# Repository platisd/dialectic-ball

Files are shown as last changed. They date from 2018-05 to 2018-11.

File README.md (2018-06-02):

# Dialectic Ball
Need to debug your code? Got stuck? Stack Overflow doesn't have the answer? Then ask Dialectic Ball!

dialectic ball

## What?
The Dialectic Ball is a physical, [Magic 8-ball](https://en.wikipedia.org/wiki/Magic_8-Ball) inspired, debugging tool for your daily code struggles! Once you are out of ideas, pick up the Dialectic Ball and explain the problem you are facing with all its details. Remember, the Dialectic Ball is a delicate and highly advanced piece of technology, thus the more information you provide it and the more you outline the problem with all its aspects, the better the chance it will be able to assist you.

Once you are done illustrating your coding issue to it, shake Dialectic Ball until the progress bar is filled and wait for the answer! If you do not get a satisfactory answer then try again. Clarify the problem better, think of any crucial details that you might have omitted during the previous run and shake again. Keep on it, until you get a witty response that helps you solve the problem!

The Dialectic Ball is more like a [rubber duck](https://en.wikipedia.org/wiki/Rubber_duck_debugging) than a [Magic 8-ball](https://en.wikipedia.org/wiki/Magic_8-Ball), so **do not ask it yes-no questions**. That wouldn't be so dialectic, would it? Of course, you can always easily modify the code and make it answer whatever you wish.

### Usage manual
1. Pick up the Dialectic Ball and face the screen
2. Admire the 8-ball intro logo
3. Dialectic Ball will prompt you to ask your question
4. Take your time and ask your question, providing all the necessary details
5. When you are done, shake the ball until the progress bar on the bottom is filled up
6. The solution to your problems is presented to you
7. If you are satisfied with the response, put the Dialectic Ball facing downwards
8. If the answer did not help, shake again when prompted

## Why?
Despite our [impressive rubber duck collection](https://i.imgur.com/bP3KeV4.jpg) at the office, sometimes they fall short on feedback and interaction. In such occasions we often utilize a colleague, but this is admittedly not the most productive use of our colleagues. Dialectic Ball intends to fill this gap, i.e. a rubber duck that is able to provide feedback. As a bonus, shaking it is fun!

## How?
Dialectic Ball is comprised of an ATtiny84, connected to a GY-61 module (based on the ADXL335 accelerometer) and an LCD screen like the ones used on the old NOKIA phones! Two AAA batteries are powering the gadget up and a [3D printed case](https://www.tinkercad.com/things/4zkr0X7OHBL) encompasses everything, giving it a hemispherical shape. The PCB that routes everything together was manufactured by [JLCPCB](https://jlcpcb.com/), who will make your prototype PCB's for just 2$ and were kind enough to sponsor the `rev. 0` boards.

From a software perspective the microcontroller mainly remains in deep sleep mode, periodically waking up to turn the accelerometer on and read its measurements. If necessary, the screen will also be powered up and the appropriate messages will be displayed to the user. Specifically, the system wakes up when the ball is not facing downwards. Furthermore, the particular LCD screen consumes minimal power, even when displaying graphics, which makes it ideal for low power applications. Overall, the average power consumption of the gadget is around 10μA, enabling it to remain operational for years on those two batteries. Last but not least, the display is controlled via the [Nokia LCD](https://github.com/platisd/nokia-5110-lcd-library) library.

### Components
* [Dialectic Ball PCB](https://github.com/platisd/dialectic-ball/tree/master/hardware/eagle)
* ATTiny84-20PU
* DIP-14 socket
* AAA battery holders (2)
* Nokia LCD screen (**Important**: Get ones that have [this](https://i.imgur.com/MhUsdiz.jpg) pin layout)
* GY-61 accelerometer module
* Tactile button
* 10KΩ resistor
* 330Ω resistor
* [3D printed case](https://www.tinkercad.com/things/4zkr0X7OHBL-magic8ball)

## Media
* [Article on platis.solutions](https://platis.solutions/blog/2018/06/02/debug-your-code-with-dialectic-ball/)
* [Demo video](https://youtu.be/oXdIgaYoSw0)

## Similar projects
* [Programmer's Magic 8-ball](https://github.com/FareedQ/Programmer-s-Magic-8-Ball)

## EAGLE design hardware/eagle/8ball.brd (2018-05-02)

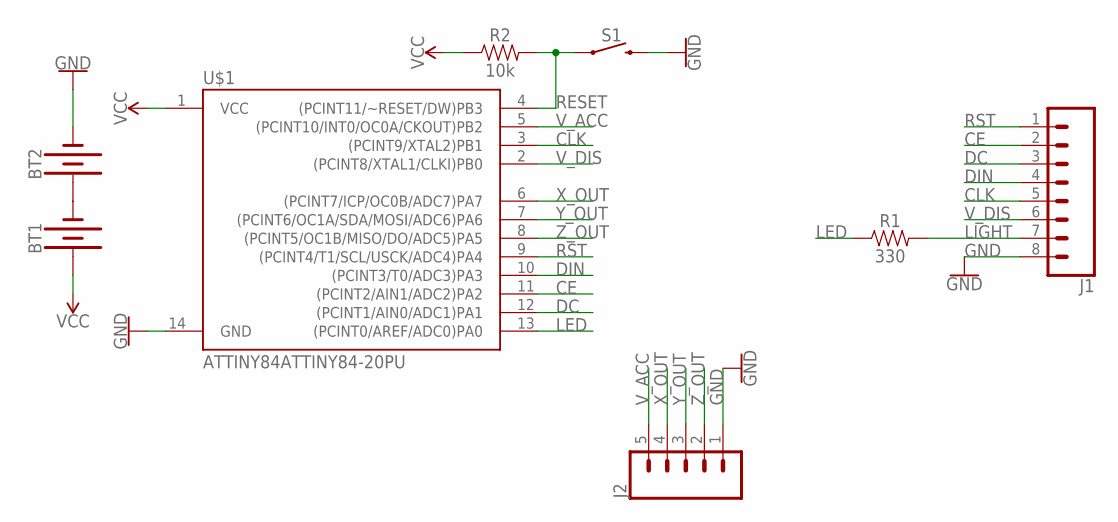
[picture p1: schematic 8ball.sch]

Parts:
BT1, BT2: BATTERY-AAA
J1: CONN_08FEMALE_LOCK; 1X08_FEMALE_LOCK
J2: CONN_05LOCK; 1X05_LOCK
R1: 330; AXIAL-0.3
R2: 10k; AXIAL-0.3
S1: MOMENTARY-SWITCH-SPST-PTH-6.0MM-KIT; TACTILE_SWITCH_PTH_6.0MM_KIT
U$1: ATTINY84ATTINY84-20PU; DIP14

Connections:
CE: J1.2, U$1.11 ((PCINT2/AIN1/ADC2)PA2)
CLK: J1.5, U$1.3 ((PCINT9/XTAL2)PB1)
DC: J1.3, U$1.12 ((PCINT1/AIN0/ADC1)PA1)
DIN: J1.4, U$1.10 ((PCINT3/T0/ADC3)PA3)
GND: BT2.GND@1 (-), J1.8, J2.1, S1.3 (2), U$1.14 (GND)
LED: R1.P$1 (1), U$1.13 ((PCINT0/AREF/ADC0)PA0)
LIGHT: J1.7, R1.P$2 (2)
unnamed: BT1.GND@1 (-), BT2.PWR@1 (+)
RESET: R2.P$2 (2), S1.1, U$1.4 ((PCINT11/~RESET/DW)PB3)
RST: J1.1, U$1.9 ((PCINT4/T1/SCL/USCK/ADC4)PA4)
VCC: BT1.PWR@1 (+), R2.P$1 (1), U$1.1 (VCC)
V_ACC: J2.5, U$1.5 ((PCINT10/INT0/OC0A/CKOUT)PB2)
V_DIS: J1.6, U$1.2 ((PCINT8/XTAL1/CLKI)PB0)
X_OUT: J2.4, U$1.6 ((PCINT7/ICP/OC0B/ADC7)PA7)
Y_OUT: J2.3, U$1.7 ((PCINT6/OC1A/SDA/MOSI/ADC6)PA6)
Z_OUT: J2.2, U$1.8 ((PCINT5/OC1B/MISO/DO/ADC5)PA5)

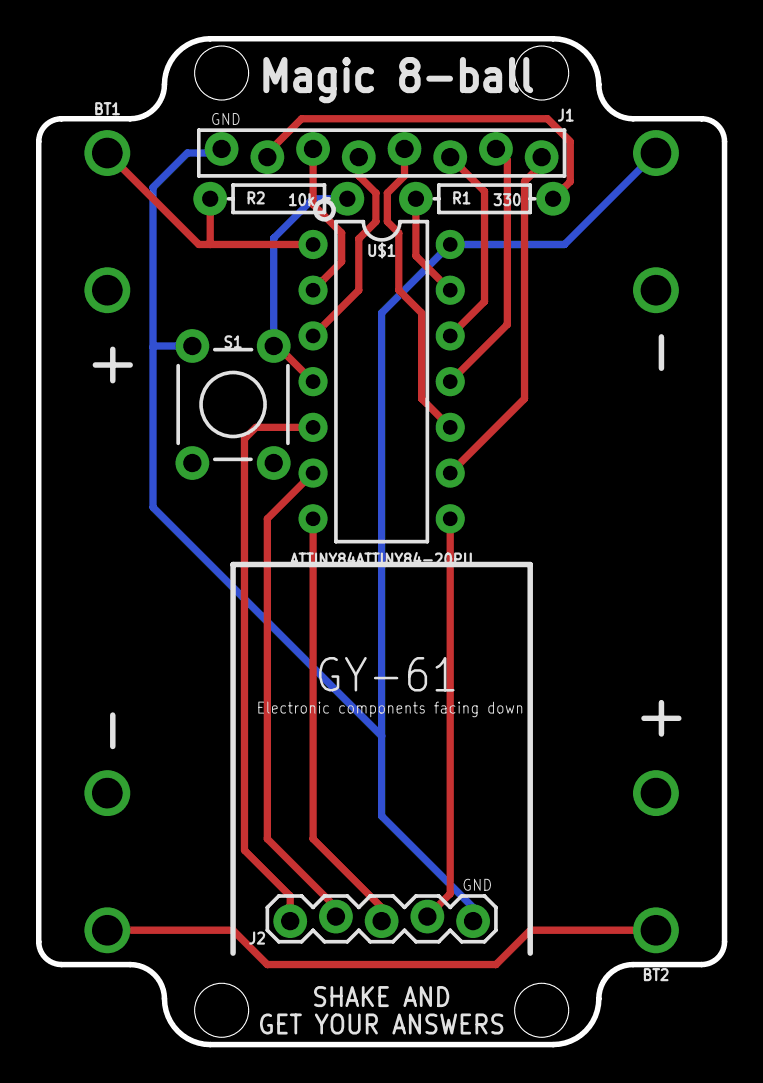
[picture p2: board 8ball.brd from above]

Board: 2 copper layers, 38.1 x 55.9 mm, 8 parts (0 on the bottom side), 16 nets.

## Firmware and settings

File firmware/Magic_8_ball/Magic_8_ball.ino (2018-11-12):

#include <Nokia_LCD.h>
#include <avr/sleep.h>
#include <avr/power.h>
#include <avr/wdt.h>
#include <avr/interrupt.h>
#include <avr/pgmspace.h>
#include <stdint.h>
#include "bitmaps.hpp"
#include "tips.hpp"

enum WatchDogTimeout {
  WDT_16ms = 0,
  WDT_32ms,
  WDT_64ms,
  WDT_128ms,
  WDT_250ms,
  WDT_500ms,
  WDT_1sec,
  WDT_2sec,
  WDT_4sec,
  WDT_8sec
};

enum RunningState {
  // Ball facing down for long amount of time
  // Screen is off
  // Slow check of accelerometer for changes
  DEEP_SLEEP,
  // Ball facing up
  // Screen is on - Waiting display
  // Fast check of accelerometer for changes
  IDLE_SCREEN,
  // Ball facing up
  // Screen is on - Game views
  // Faster check of accelerometer for changes
  PLAYING,
};

const uint8_t V_ACC_PIN = 8; // PB2
const uint8_t CLK_PIN = 9; // PB1
const uint8_t V_DIS_PIN = 10; // PB0
const uint8_t X_OUT_PIN = A7; // PA7
const uint8_t Y_OUT_PIN = A6; // PA6
const uint8_t Z_OUT_PIN = A5; // PA5
const uint8_t RST_PIN = 4; // PA4
const uint8_t DIN_PIN = 3; // PA3
const uint8_t CE_PIN = 2; // PA2
const uint8_t DC_PIN = 1; // PA1
const uint8_t LED_PIN = 0; // PA0

// Input & output pins directly controlled in this scope
const uint8_t OUTPUT_PINS[] = {V_ACC_PIN, V_DIS_PIN, LED_PIN};
const uint8_t INPUT_PINS[] = {X_OUT_PIN, Y_OUT_PIN, Z_OUT_PIN};
const uint8_t LCD_DATA_PINS[] = {CLK_PIN, DIN_PIN, DC_PIN, CE_PIN, RST_PIN};

// The experimentally determined Z-axis value over which we consider
// ourselves to be facing up
const unsigned int MIN_FACING_UP_THRESHOLD = 470;
// The minimum acceleration delta (on X,Y,Z axes) to be considered as a movement
// The smaller the number the easier a "movement" will be registered
const unsigned int MOVEMENT_ACCELERATION_THRESHOLD = 25; // Experimentally determined
// The amount of detected movements needed to start a game
const uint8_t AMOUNT_OF_MOVEMENTS_THRESHOLD = 5;
// How much to wait before using the accelerometer in milliseconds
const unsigned long ACCELEROMETER_BOOTUP_TIME = 15;
// Sleep duration while in DEEP_SLEEP mode
const unsigned long DEEP_SLEEP_INTERVAL = 1000;
// Sleep duration while in IDLE_SCREEN mode
const unsigned long IDLE_SCREEN_INTERVAL = 100;
// Sleep duration while in PLAYING mode
const unsigned long TIP_INTERVAL = 2500;
const uint8_t TIPS_LENGTH = 50; // The tips' max length in characters
const unsigned long EIGHTBALL_SLEEP = 500; // How long to display the 8ball logo in milliseconds

volatile bool watchdogBarked = false;

Nokia_LCD lcd(CLK_PIN /* CLK */, DIN_PIN /* DIN */, DC_PIN /* DC */, CE_PIN /* CE */, RST_PIN /* RST */);
RunningState currentState = DEEP_SLEEP;
unsigned int amountOfMovements = 0;
int previousAcceleration = 0;
bool justWokeUp = true; // A flag to indicate whether the screen is turning on just now

/**
  Watchdog interrupt routine to be triggered when watchdog times out.
*/
ISR(WDT_vect) {
  watchdogBarked = true;
}

/**
    Sets up watchdog to be triggered (once) after the specified time
    @param wdt  the watchdog timeout duration
*/
void triggerWatchDogIn(WatchDogTimeout wdt) {
  // Adopted from InsideGadgets (www.insidegadgets.com)
  byte timeoutVal = wdt & 7;
  if (wdt > 7) {
    timeoutVal |= (1 << 5);
  }
  timeoutVal |= (1 << WDCE);

  MCUSR &= ~(1 << WDRF);
  WDTCSR |= (1 << WDCE) | (1 << WDE); // Start timed sequence
  WDTCSR = timeoutVal;
  WDTCSR |= _BV(WDIE);
  wdt_reset(); // Pat the dog
}

/**
   A utility method to derive a watchdog timeout's duration
   @param wdt the watchdog timeout
   @return    the amount of milliseconds corresponding to a watchdog timeout
*/
unsigned long getTimeoutDuration(WatchDogTimeout wdt) {
  return 1 << (wdt + 4);
}

void goToSleep() {
  set_sleep_mode(SLEEP_MODE_PWR_DOWN);
  power_all_disable ();
  sleep_enable();
  sleep_cpu(); // Sleep here and wait for the interrupt
  sleep_disable();
  power_all_enable(); // power everything back on
}

/**
   Blocks and stays in deep sleep until the specified time has elapsed
   using the current watchdog timeout.
   @param sleepDuration     how long to stay in deep sleep in milliseconds
   @param timeoutInterval   the watchdog timeout interval
*/
void stayInDeepSleepFor(unsigned long sleepDuration, WatchDogTimeout timeoutInterval = WDT_16ms) {
  unsigned long sleepTime = 0;

  // Start by triggering the watchdog to wake us up every `timeoutInterval`
  triggerWatchDogIn(timeoutInterval);
  while (sleepTime <= sleepDuration) {
    // Sleep until an interrupt occurs (external, change or watchdog)
    goToSleep();
    // Verify we woke up because of the watchdog and not
    // a spurious wake up due to some other unrelated interrupt.
    if (watchdogBarked) {
      // Note down that we have processed the watchdog bark
      watchdogBarked = false;
      // Increase the time we have already slept
      sleepTime += getTimeoutDuration(timeoutInterval);
    }
  }
  wdt_disable(); // Disable watchdog so it stops barking
}

/*** Helper functions ***/
void turnScreenOn() {
  digitalWrite(V_DIS_PIN, HIGH);
}

void turnScreenOff() {
  digitalWrite(V_DIS_PIN, LOW);
  for (auto pin : LCD_DATA_PINS) {
    digitalWrite(pin, LOW);
  }
}

void turnBacklightOn() {
  digitalWrite(LED_PIN, LOW);
}

void turnBacklightOff() {
  digitalWrite(LED_PIN, HIGH);
}

void turnAccelerometerOn() {
  // Accelerometer needs some few milliseconds to get ready
  // so we need to make sure that we give it this time
  digitalWrite(V_ACC_PIN, HIGH);
  stayInDeepSleepFor(ACCELEROMETER_BOOTUP_TIME, WDT_16ms); // Give the accelerometer some time to boot
  enableADC();
}

void turnAccelerometerOff() {
  disableADC();
  digitalWrite(V_ACC_PIN, LOW);
}

unsigned int getAccelerationX() {
  return analogRead(X_OUT_PIN);
}

unsigned int getAccelerationY() {
  return analogRead(Y_OUT_PIN);
}

unsigned int getAccelerationZ() {
  return analogRead(Z_OUT_PIN);
}

unsigned int getAccelerationXYZ() {
  return getAccelerationX() + getAccelerationY() + getAccelerationZ();
}

void disableADC() {
  ADCSRA &= ~(1 << ADEN);
}

void enableADC() {
  ADCSRA |= (1 << ADEN);
}

bool isFacingUp() {
  return getAccelerationZ() >= MIN_FACING_UP_THRESHOLD;
}

/*** Helper functions ***/

void setup() {
  // Set pin directions
  for (auto pin : INPUT_PINS) {
    pinMode(pin, INPUT);
  }
  for (auto pin : OUTPUT_PINS) {
    pinMode(pin, OUTPUT);
  }

  // Disable digital pin buffers for analog pins
  // to save some power, since we are doing only analog readings
  bitSet(DIDR0, ADC5D); // Disable digital buffer on A5
  bitSet(DIDR0, ADC6D); // Disable digital buffer on A6
  bitSet(DIDR0, ADC7D); // Disable digital buffer on A7

  turnBacklightOff();
}

void loop() {
  switch (currentState) {
    case DEEP_SLEEP:
      {
        turnAccelerometerOn();
        // Store whether it is facing up in a variable
        // so we can turn the accelerometer off right away
        // before printing to the screen or sleeping more
        bool facingUp = isFacingUp();
        turnAccelerometerOff();
        if (facingUp) {
          // Prepare the transition to the IDLE_SCREEN state
          currentState = IDLE_SCREEN;
          // Prepare the screen
          turnScreenOn();
          lcd.begin();
          lcd.setContrast(60);
          // If we just woke up, display the 8-ball logo to the user
          if (justWokeUp) {
            justWokeUp = false;
            lcd.draw(eightball, sizeof(eightball) / sizeof(unsigned char));
            stayInDeepSleepFor(EIGHTBALL_SLEEP, WDT_500ms);
            lcd.clear();
          } else {
            lcd.clear(); // Clear the screen for the upcomming prompt
          }
          lcd.draw(ask_question, sizeof(ask_question) / sizeof(unsigned char));
          lcd.setCursor(3, 5); // Set the cursor to the start of the progress bar
          lcd.draw(left_side_bar, sizeof(left_side_bar) / sizeof(unsigned char));

          // Initialize the movement related variables
          amountOfMovements = 0;
          turnAccelerometerOn();
          previousAcceleration = getAccelerationXYZ(); // Get some initial measurement
          turnAccelerometerOff();
        } else {
          turnScreenOff();
          stayInDeepSleepFor(DEEP_SLEEP_INTERVAL, WDT_1sec);
          justWokeUp = true;
        }
      }
      break;
    case IDLE_SCREEN:
      {
        stayInDeepSleepFor(IDLE_SCREEN_INTERVAL, WDT_32ms);
        // Check for movements
        // Calculate the current delta in acceleration
        turnAccelerometerOn();
        int currentAcceleration = getAccelerationXYZ();
        turnAccelerometerOff();
        int accelerationDelta = currentAcceleration - previousAcceleration;
        previousAcceleration = currentAcceleration;

        // Determine whether the current difference in acceleration constitutes a movement
        // and whether we need to transist to a different state
        if (abs(accelerationDelta) >= MOVEMENT_ACCELERATION_THRESHOLD) {
          if (++amountOfMovements >= AMOUNT_OF_MOVEMENTS_THRESHOLD) {
            currentState = PLAYING;
          }
          // Print out visual feedback/affirmation for the user's movement
          lcd.draw(progress_bar, sizeof(progress_bar) / sizeof(unsigned char));
        } else {
          // If there hasn't been any movement, check to see if we are facing down therefore
          // should go to sleep
          turnAccelerometerOn();
          bool facingUp = isFacingUp();
          turnAccelerometerOff();
          if (!facingUp) {
            currentState = DEEP_SLEEP;
          }
        }
      }
      break;
    case PLAYING:
      {
        lcd.clear();
        // Display a very helpful message to the user
        // Randomly select a helpful tip
        randomSeed(previousAcceleration + millis());
        uint8_t randomTip = random(0, AMOUNT_OF_TIPS);

        // Read the tip from flash memory
        char tipsBuffer[TIPS_LENGTH];
        strcpy_P(tipsBuffer, (char*)pgm_read_word(&(TIPS[randomTip])));
        // Place a null terminator in the end just to be safe
        tipsBuffer[TIPS_LENGTH - 1] = '\0';
        lcd.print(tipsBuffer);

        // Draw a text-face under the tip to make it more appealing 乁( ◔ ౪◔)「
        uint8_t randomFace = random(0, NUM_OF_FACES);
        // Print the face on the last two rows (make sure not to overlay the text)
        lcd.setCursor(0, 4);
        lcd.draw(pgm_read_ptr_near(&(FACES[randomFace])), FACE_SIZE);

        stayInDeepSleepFor(TIP_INTERVAL, WDT_1sec);
        currentState = DEEP_SLEEP;
      }
      break;
    default:
      break;
  }
}

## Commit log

2018-05-02 Add rev.0 hardware
    [8ball.brd, 8ball.sch]
2018-05-27 Fix current leak during deep sleep
    Unusually high power consumption (10-20ma) was observed when the system
    was put in DEEP_SLEEP mode after having previously been operational.
    The cause was that the pins controlling the data on the LCD screen were
    left in an undefined state after turning the screen on. As the Nokia_LCD
    class neither handles the screen when completely powered off nor cares for
    the state of the pins, its user has to set the state of those pins themselves.
    This could possibly be an interesting addition to the Nokia_LCD library,
    i.e. handling the power as well as the backlight pins.
    [Magic_8_ball.ino]
2018-05-29 Decrease the overall reaction times to make the ball snappier
    [Magic_8_ball.ino]
2018-05-30 Add information on the display driver library
2018-05-30 Add link to 3d printed case
2018-11-12 Avoid clearing the screen when not necessary
    When drawing the 8ball logo, it is not necessary to clear the screen before that
    since whatever leftovers exist will be overwritten by the drawing.
    [Magic_8_ball.ino]

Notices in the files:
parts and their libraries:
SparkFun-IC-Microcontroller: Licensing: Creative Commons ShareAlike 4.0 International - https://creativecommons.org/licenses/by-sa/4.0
